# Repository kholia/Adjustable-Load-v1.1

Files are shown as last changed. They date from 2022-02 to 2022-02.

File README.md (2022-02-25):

### Variable Electronic Load

This variable electronic load helps with testing power supplies, and batteries.

Motivation: RIGOL DC Electronic Load-DL3021 costs ~50k - this project costs
nothing in comparison, and does the job in typical amateur radio contexts just
fine.

Rating: 20A @ 30V depending upon the heatsink.

Testing notes (Dhiru): I have tested my build up to 5A @ around 20v.

This is an improved version of https://www.instructables.com/DIY-Adjustable-Constant-Load-Current-Power/. All
credit goes to `GreatScott` for coming up with this project.

Note: The 3D renderings are *only* published to help with the manual layout work on
Zero-PCBs. All screenshots are clickable and zoomable.

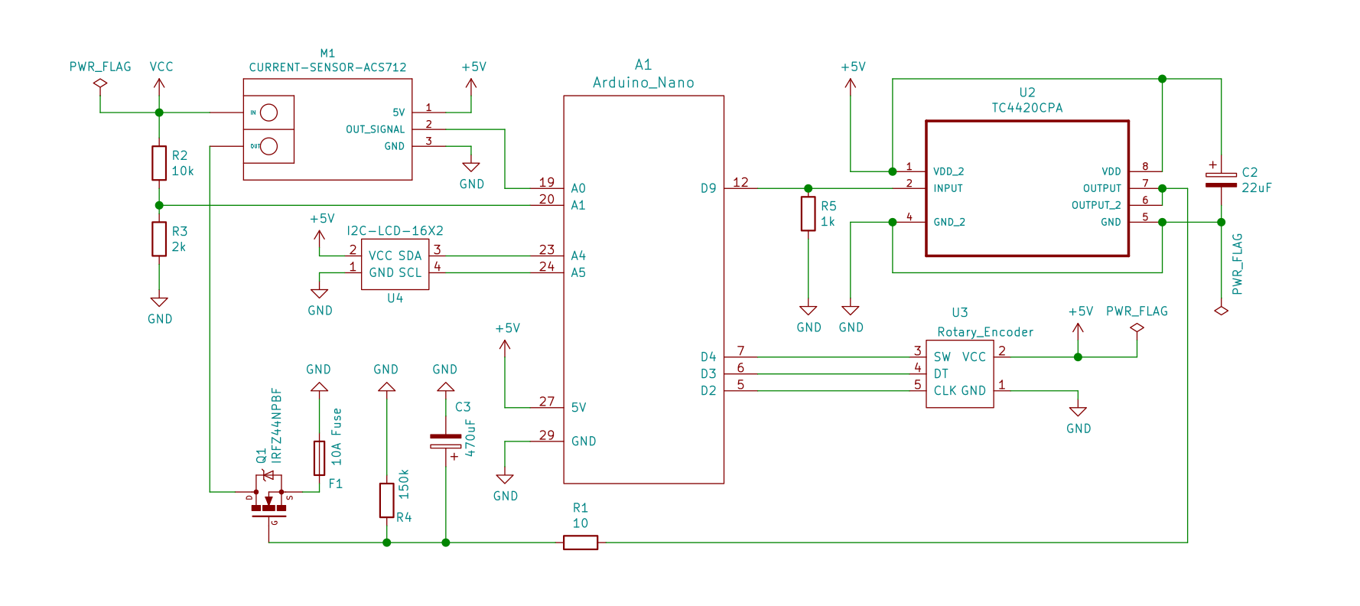
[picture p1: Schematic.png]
Schematic

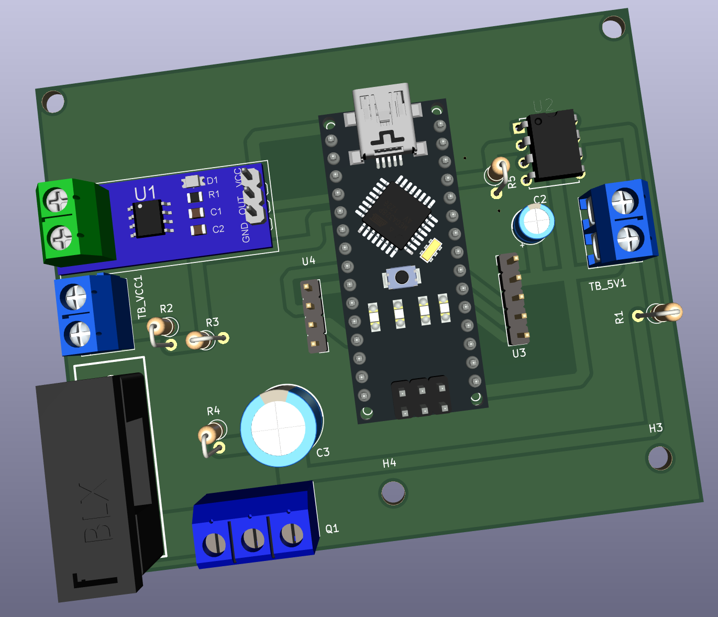
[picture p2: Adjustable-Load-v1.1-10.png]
3D rendering


See `Adjustable-Load-v1.1.pdf` for details.

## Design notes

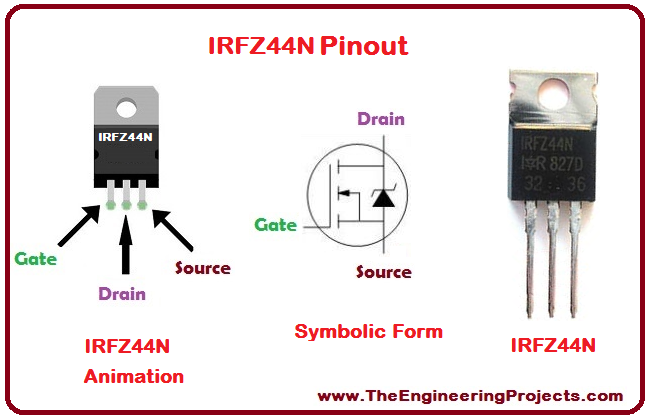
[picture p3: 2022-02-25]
images/IRFZ44N pinout.png

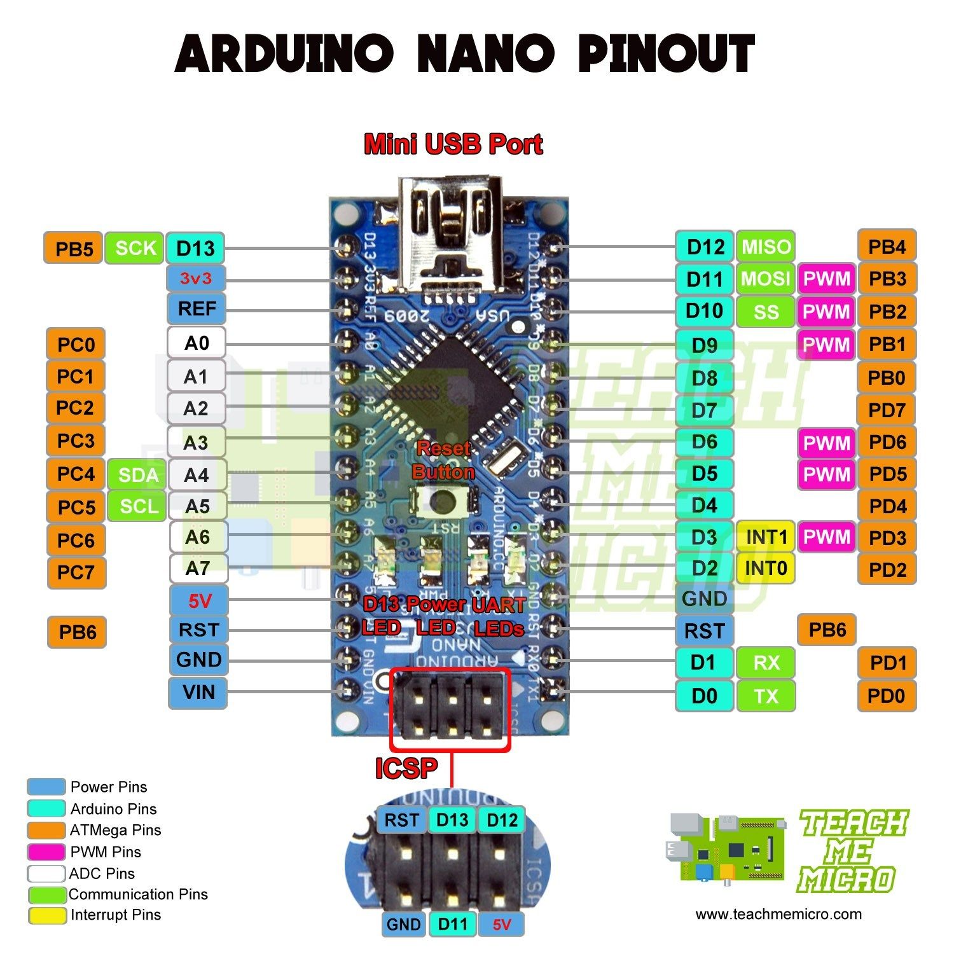
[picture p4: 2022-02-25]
images/Arduino Nano Pinout.jpg

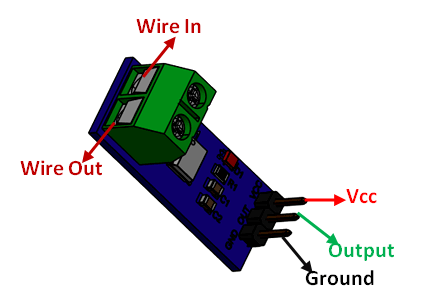
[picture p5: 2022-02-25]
images/ACS712-Current-Sensor-Pinout.png

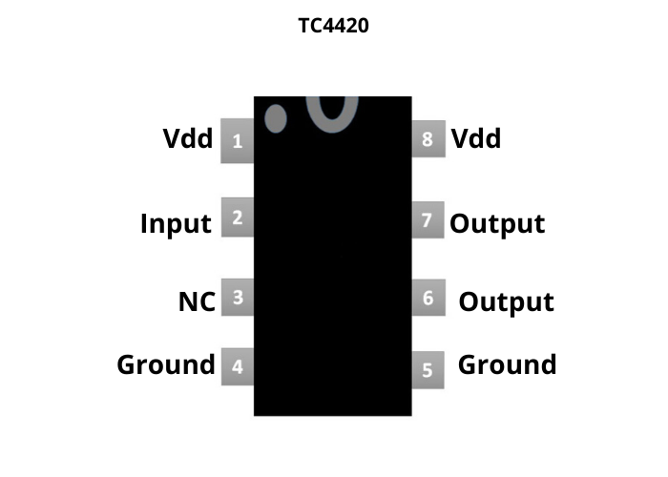
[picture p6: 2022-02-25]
images/TC4420-IC-Pinout.png

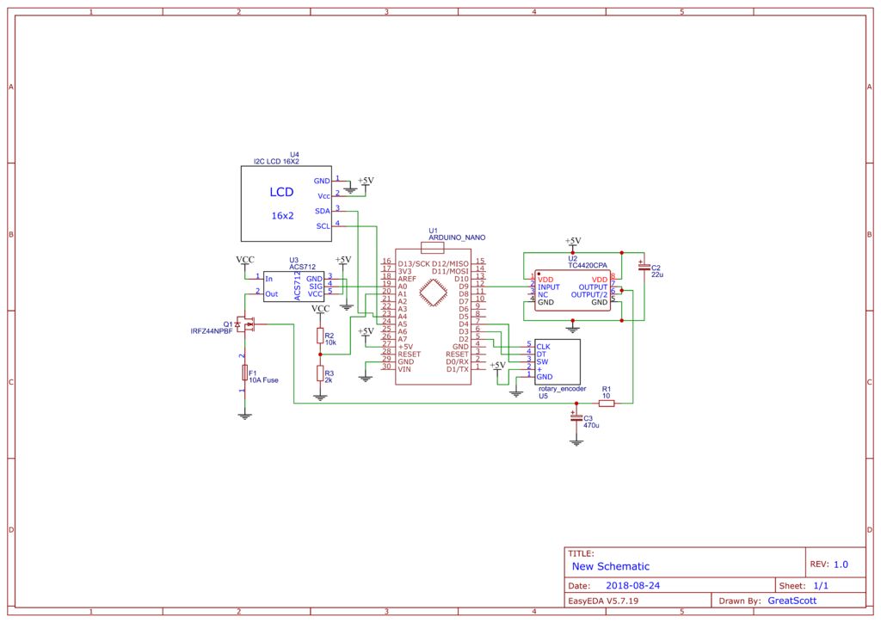
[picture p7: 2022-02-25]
Dummy Load Schematic.jpg

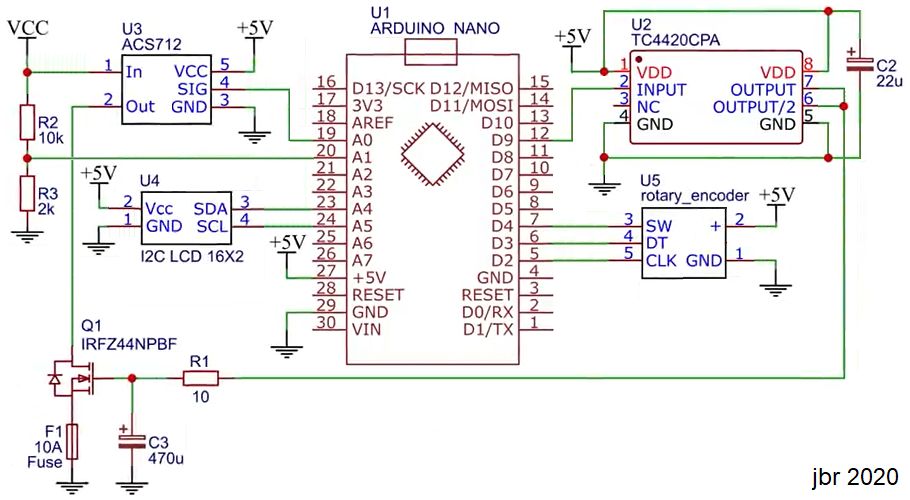
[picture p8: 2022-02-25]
Redrawn Schematic.jpg

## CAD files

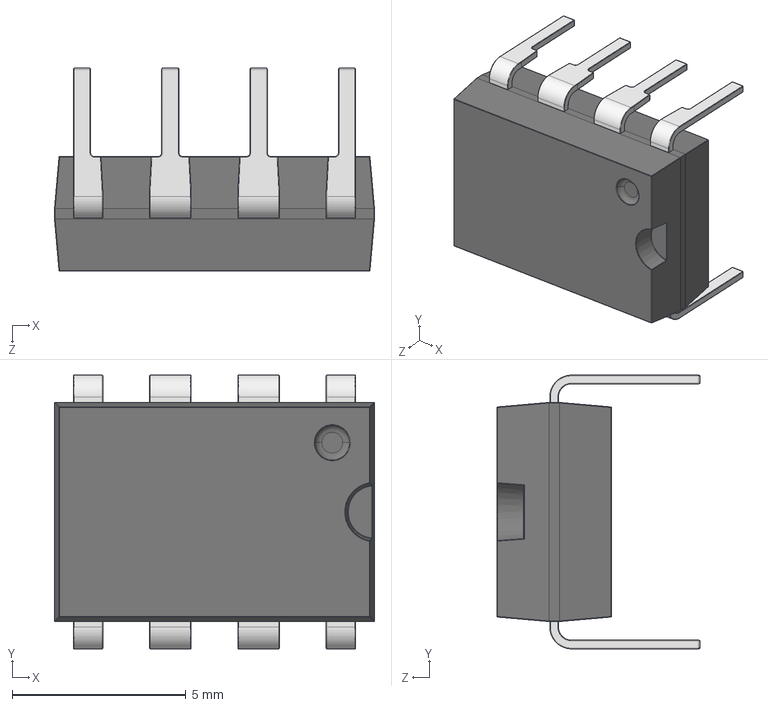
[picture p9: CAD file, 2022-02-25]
models/DIP8.STEP
9.20 x 7.87 x 5.85 mm

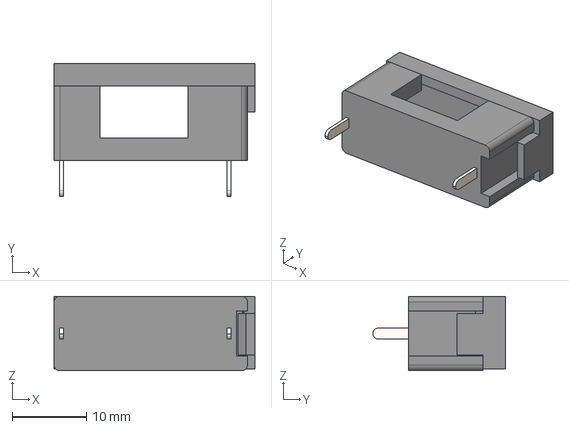
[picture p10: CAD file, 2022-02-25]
models/Fuse Holder.step
27.0 x 17.8 x 10.0 mm

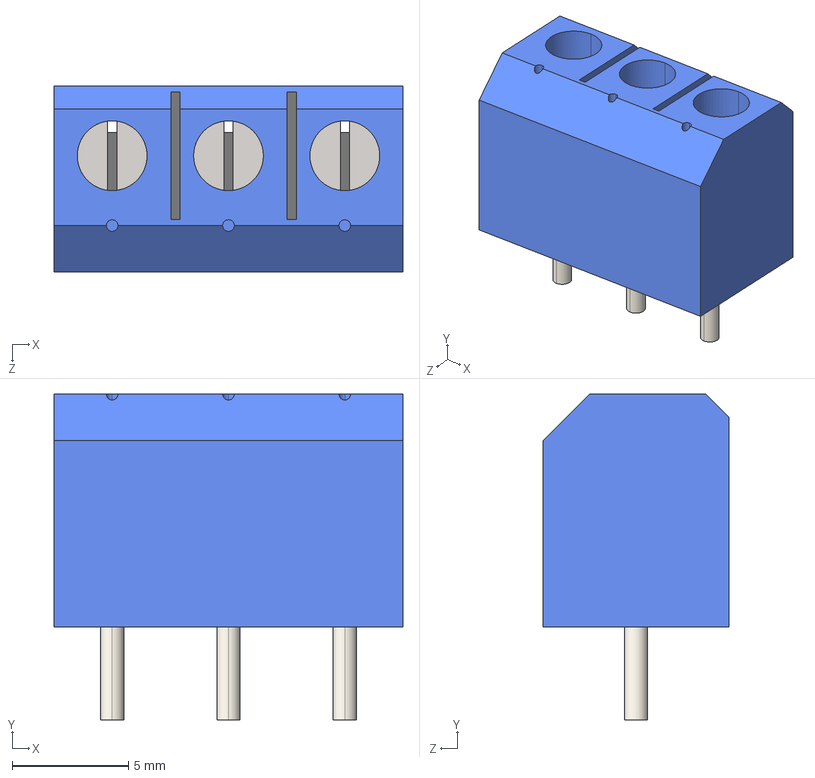
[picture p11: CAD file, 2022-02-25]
models/bornera de 3 terminales v2.0.STEP
15.0 x 14.0 x 8.00 mm

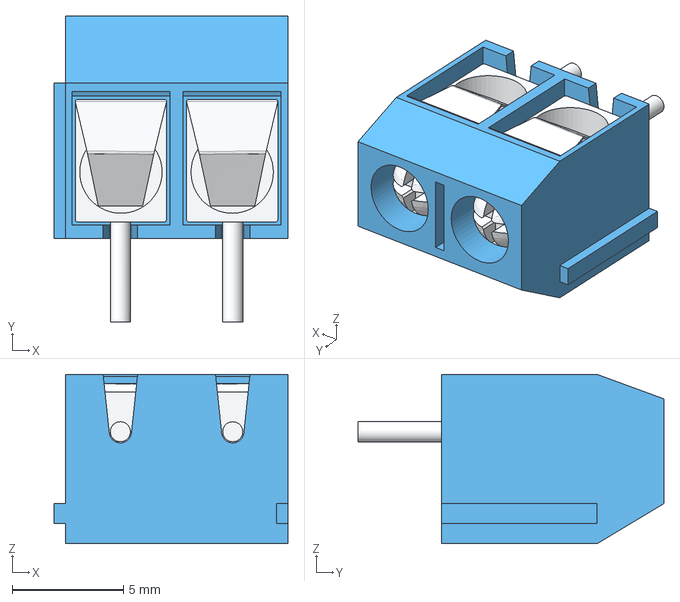
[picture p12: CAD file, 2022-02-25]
models/bornera.step
10.5 x 13.8 x 7.60 mm

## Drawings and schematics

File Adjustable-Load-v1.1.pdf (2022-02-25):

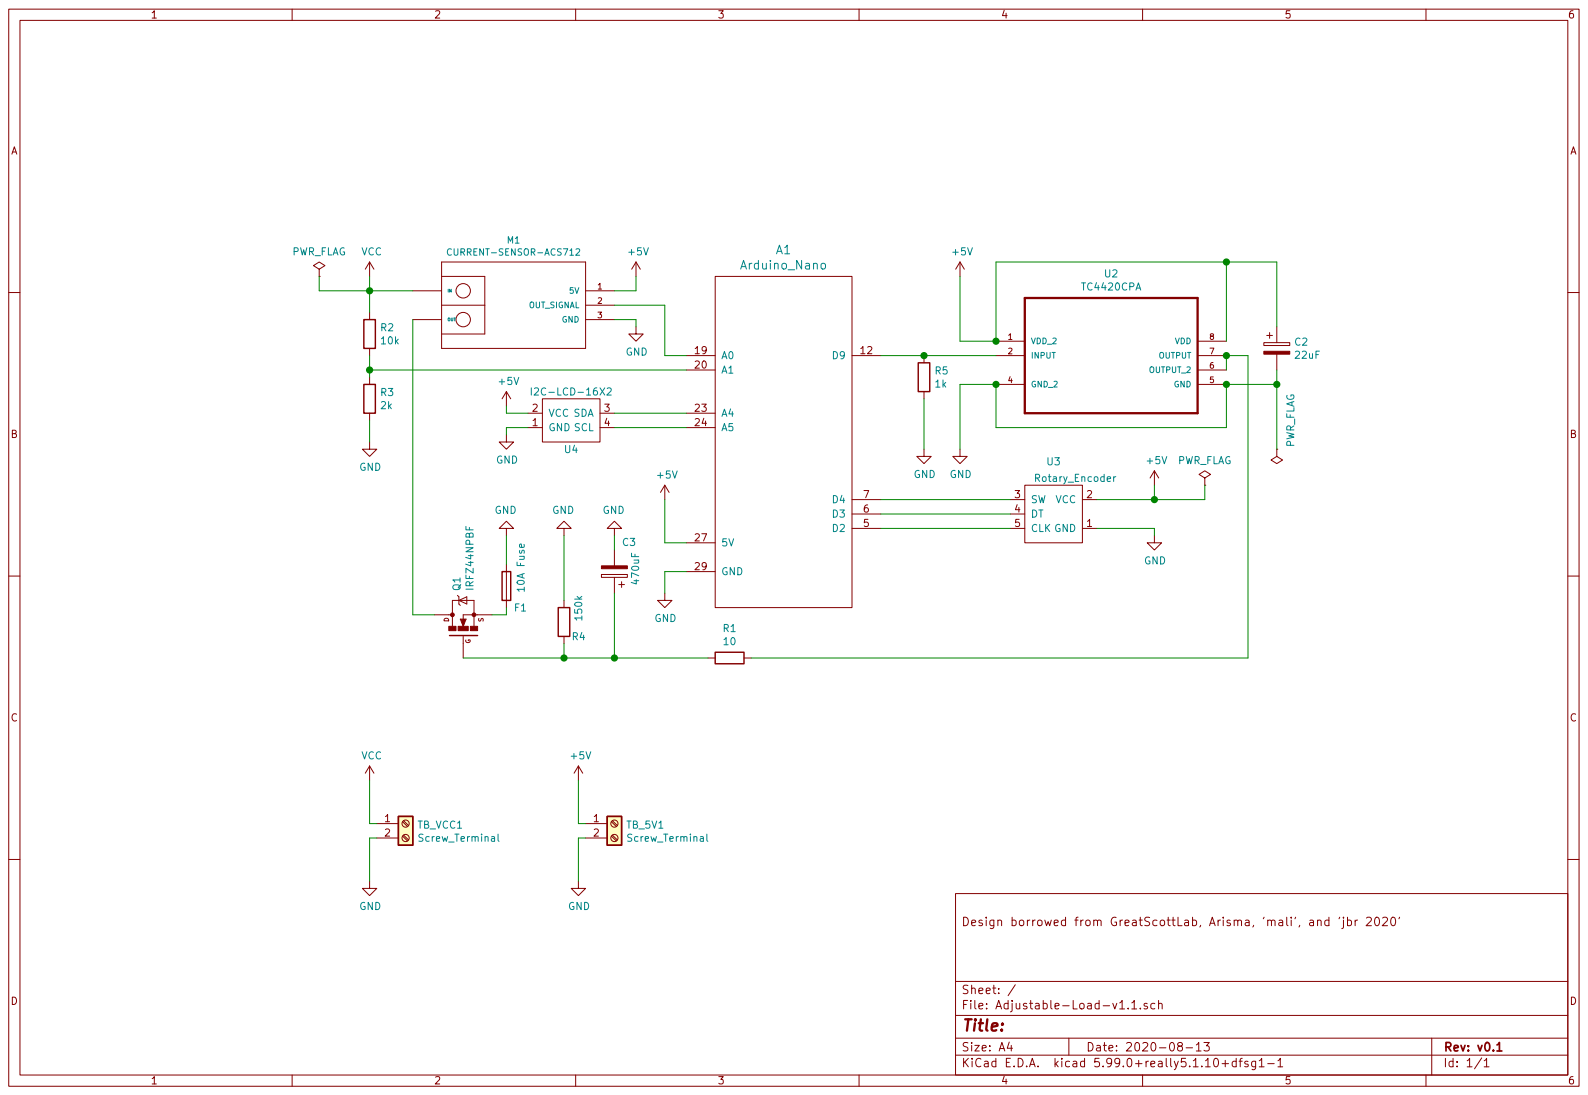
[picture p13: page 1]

File: Adjustable-Load-v1.1.sch Sheet: / Design borrowed from GreatScottLab, Arisma, 'mali', and 'jbr 2020' C3 470uF

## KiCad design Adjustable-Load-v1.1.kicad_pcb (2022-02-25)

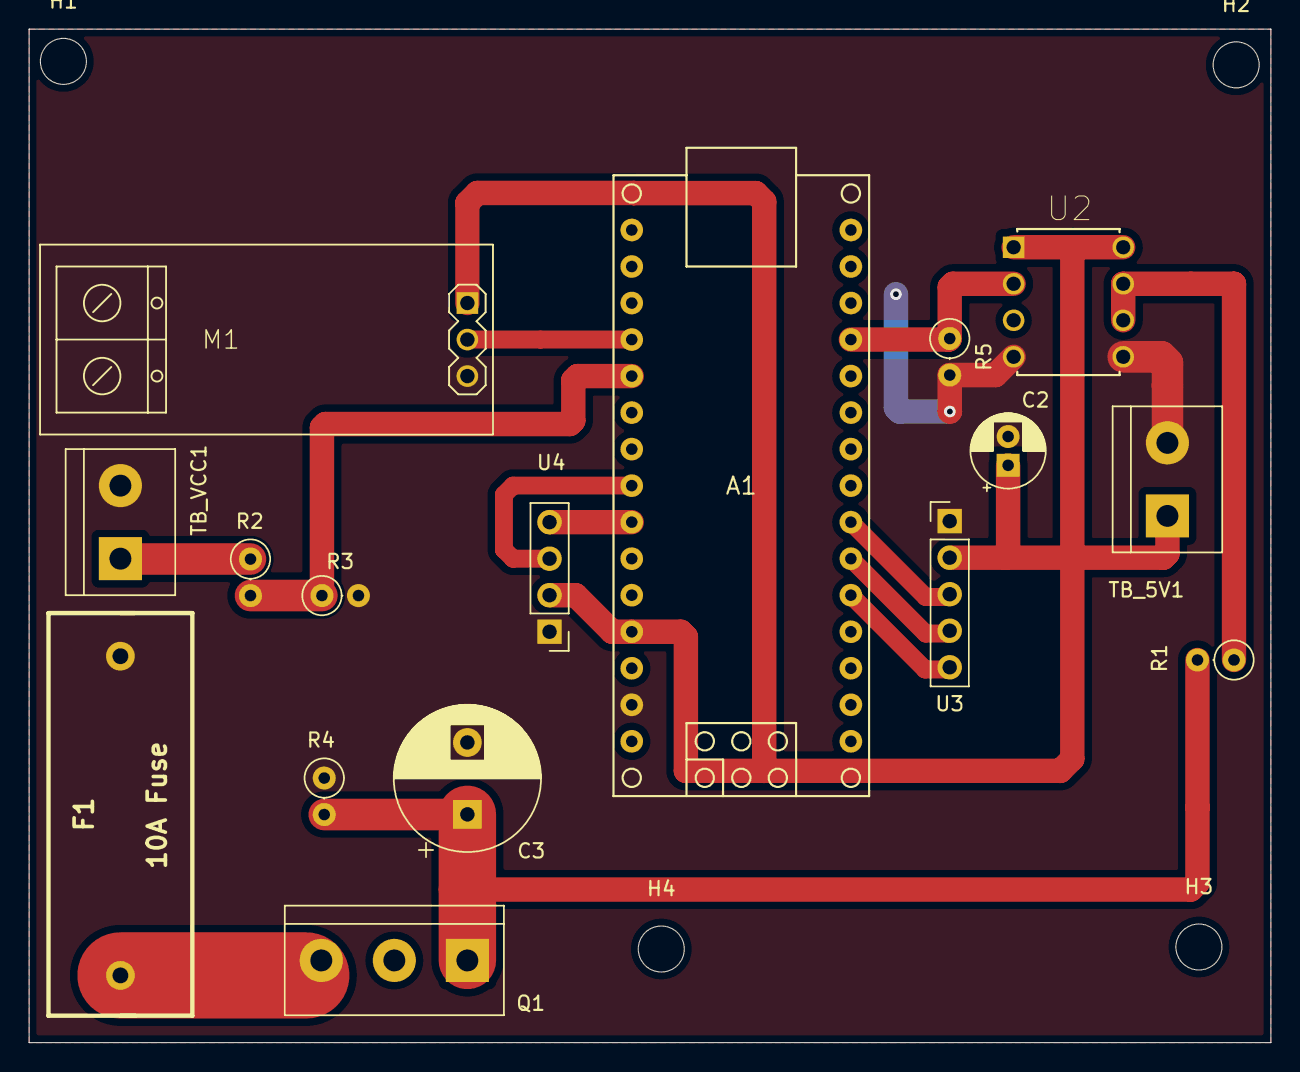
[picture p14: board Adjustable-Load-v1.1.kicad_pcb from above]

Board: 2 copper layers, 86.4 x 70.5 mm, 20 parts (0 on the bottom side), 14 nets.

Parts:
A1: Arduino_Nano; arduino_nano
C2: 22uF; CP_Radial_D5.0mm_P2.00mm
C3: 470uF; CP_Radial_D10.0mm_P5.00mm
F1: 10A Fuse; BLX-A
H1, H2, H3, H4: MountingHole; MountingHole_3.2mm_M3
M1: CURRENT-SENSOR-ACS712
Q1: IRFZ44NPBF; TerminalBlock_bornier-3_P5.08mm
R1: 10; R_Axial_DIN0207_L6.3mm_D2.5mm_P2.54mm_Vertical
R2: 10k; R_Axial_DIN0207_L6.3mm_D2.5mm_P2.54mm_Vertical
R3: 2k; R_Axial_DIN0207_L6.3mm_D2.5mm_P2.54mm_Vertical
R4: 150k; R_Axial_DIN0207_L6.3mm_D2.5mm_P2.54mm_Vertical
R5: 1k; R_Axial_DIN0207_L6.3mm_D2.5mm_P2.54mm_Vertical
TB_5V1: Screw_Terminal; TerminalBlock_bornier-2_P5.08mm
TB_VCC1: Screw_Terminal; TerminalBlock_bornier-2_P5.08mm
U2: TC4420CPA; DIP254P762X533-8
U3: Rotary_Encoder; PinHeader_1x05_P2.54mm_Vertical
U4: I2C-LCD-16X2; PinHeader_1x04_P2.54mm_Vertical

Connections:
+5V: A1.27 (5V), C2.1, M1.1 (5V), TB_5V1.1, U2.1 (VDD_2), U2.8 (VDD), U3.2 (VCC), U4.2 (VCC)
GND: A1.29 (GND), C2.2, C3.2, F1.1, M1.3 (GND), R3.2, R4.1, R5.2, TB_5V1.2, TB_VCC1.2, U2.4 (GND_2), U2.5 (GND), U3.1 (GND), U4.1 (GND)
unnamed: A1.5 (D2), U3.5 (CLK)
unnamed: A1.6 (D3), U3.4 (DT)
unnamed: A1.7 (D4), U3.3 (SW)
unnamed: A1.12 (D9), R5.1, U2.2 (INPUT)
unnamed: A1.19 (A0), M1.2 (OUT_SIGNAL)
unnamed: A1.20 (A1), R2.2, R3.1
unnamed: A1.23 (A4), U4.3 (SDA)
unnamed: A1.24 (A5), U4.4 (SCL)
unnamed: C3.1, Q1.1, R1.2, R4.2
unnamed: F1.2, Q1.3
unnamed: R1.1, U2.6 (OUTPUT_2), U2.7 (OUTPUT)
VCC: R2.1, TB_VCC1.1

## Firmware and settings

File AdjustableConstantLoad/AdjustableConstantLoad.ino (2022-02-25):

// https://www.instructables.com/id/DIY-Adjustable-Constant-Load-Current-Power/

#include <Wire.h>
#include "LiquidCrystal_I2C.h"
LiquidCrystal_I2C lcd(0x27, 16, 2);

#define clk 2
#define dt 3
#define sw 4
#define pwm 9
#define currentsense A0
#define voltagesense A1

char screen = 0;
char arrowpos = 0;
float power = 2.5;
float current = 0.250;
float curcurrent = 0;
float curpower = 0;
float curvoltage = 0;
float curcurrentraw = 0;
float zerocurrent = 510.25;  // was 514
float curvoltraw = 0;
int counter = 0;
volatile boolean currentmode = false;
volatile boolean powermode = false;
volatile boolean TurnDetected = false;
volatile boolean up = false;
volatile boolean button = false;
const unsigned char PS_128 = (1 << ADPS2) | (1 << ADPS1) | (1 << ADPS0);

/*

   Sensitivity of current sensor:

    5A = 185.00

   20A = 100.00

   30A = 66.00;

*/

float cursense = 185.00;  // for 5A current sensor

byte customChar1[8] = {
  0b10000,
  0b11000,
  0b11100,
  0b11110,
  0b11110,
  0b11100,
  0b11000,
  0b10000
};

byte customChar2[8] = {
  0b00100,
  0b01110,
  0b11111,
  0b00000,
  0b00000,
  0b11111,
  0b01110,
  0b00100,
};

ISR(PCINT2_vect) {
  if (digitalRead(sw) == LOW) {
    button = true;
  }
}

void isr0 ()  {
  TurnDetected = true;
  up = (digitalRead(clk) == digitalRead(dt));
}

void setup() {
  Serial.begin(115200);
  lcd.begin();
  pinMode(sw, INPUT_PULLUP);
  pinMode(clk, INPUT);
  pinMode(dt, INPUT);
  pinMode(pwm, OUTPUT);
  pinMode(currentsense, INPUT);
  digitalWrite(pwm, LOW);
  ADCSRA &= ~PS_128;
  ADCSRA |= (1 << ADPS1) | (1 << ADPS0);
  PCICR |= 0b00000100;
  PCMSK2 |= 0b00010000;   // turn o PCINT20(D4)
  attachInterrupt(0, isr0, RISING);
  TCCR1A = 0;
  TCCR1A = (1 << COM1A1) | (1 << WGM11);
  TCCR1B = 0;
  TCCR1B = (1 << WGM13) | (1 << WGM12) | (1 << CS10);
  ICR1 = 2047;
  OCR1A = 0;
  lcd.createChar(0, customChar1);
  lcd.createChar(1, customChar2);
  lcd.clear();
  lcd.print(" ADJ CONST LOAD");
  delay(2000);
  screen0();
  lcd.setCursor(0, 0);
  lcd.write((uint8_t)0);

  // Read the analog input a few times to makes sure that we get
  // a good zero adjustment from nominal center value. There should be no
  // current flowing while this is happening.
  // for (uint8_t i = 1; i <= 10; i++) {
  //    uint16_t error = 512 - analogRead(SENSOR_PIN);
  //    sensorZeroAdj = ((sensorZeroAdj * (i-1)) + error)/i;
  // }
}

void loop() {

  if (currentmode) {
    // take 20 readings of current
    curcurrentraw = 0;
    for (int i = 0; i < 20; i++) {
      analogRead(currentsense);
      curcurrentraw += analogRead(currentsense);
    }
    // 5V -> 5000mV
    // 100.00 -> sensitivity (20A current sensor)
    // curcurrent = (((curcurrentraw/20) - zerocurrent) * (5000.00 / 1023.00) / 100.00);
    curcurrent = (((curcurrentraw / 20) - zerocurrent) * (5000.00 / 1023.00) / cursense);

    if (curcurrent < 0)
      curcurrent = 0;

    // curcurrentraw = analogRead(currentsense);
    // curcurrent = ((curcurrentraw - zerocurrent) * (5000.00 / 1023.00) / 100.00);
    //Serial.print(zerocurrent);
    //Serial.print("  ");
    //Serial.print(curcurrentraw);
    //Serial.print("  ");
    //Serial.println(curcurrent);
    if (counter == 5000) {
      lcd.setCursor(4, 1);
      lcd.print(curcurrent);
      lcd.print("A ");
      counter = 0;
      Serial.println(curcurrentraw / 20);
      Serial.println(curcurrent);
    }
    if (curcurrent < current) {
      OCR1A++;
    }
    else {
      if (OCR1A > 0) {
        OCR1A = OCR1A - 1;
      } else {
        OCR1A = 0;
      }
    }
    counter++;
    delayMicroseconds(100);
  }

  if (powermode) {
    /* curcurrentraw = analogRead(currentsense);
       curcurrent = ((curcurrentraw - zerocurrent) * (5000.00 / 1023.00) / 100.00); */
    // take 20 readings of current
    curcurrentraw = 0;
    for (int i = 0; i < 20; i++) {
      curcurrentraw += analogRead(currentsense);
    }
    curcurrent = (((curcurrentraw / 20) - zerocurrent) * (5000.00 / 1023.00) / 100.00);

    if (curcurrent < 0)
      curcurrent = 0;
    /* read twice */
    curvoltraw = analogRead(voltagesense);
    curvoltraw = analogRead(voltagesense);
    curvoltage = curvoltraw * (5000.00 / 1023.00) * 7.20 / 1000.00;
    curpower = curvoltage * curcurrent;
    //Serial.println(curpower);
    if (counter == 5000) {
      lcd.setCursor(4, 1);
      lcd.print(curpower);
      lcd.print("W ");
      counter = 0;

      Serial.println(curcurrentraw / 20);
      Serial.println(curcurrent);
      Serial.println(curvoltraw);
      Serial.println(curvoltage);
      Serial.println(curpower);
      Serial.println("-----");
    }
    if (curpower < power) {
      OCR1A++;
    }
    else {
      if (OCR1A > 0) {
        OCR1A = OCR1A - 1;
      } else {
        OCR1A = 0;
      }
    }
    counter++;
    delayMicroseconds(100);
  }

  if (TurnDetected) {
    delay(200);
    switch (screen) {
      case 0:
        switch (arrowpos) {
          case 0:
            if (!up) {
              screen0();
              lcd.setCursor(0, 1);
              lcd.write((uint8_t)0);
              arrowpos = 1;
            }
            break;
          case 1:
            if (up) {
              screen0();
              lcd.setCursor(0, 0);
              lcd.write((uint8_t)0);
              arrowpos = 0;
            }
            break;
        }
        break;
      case 1:
        switch (arrowpos) {
          case 0:
            if (!up) {
              screen1();
              lcd.setCursor(0, 1);
              lcd.write((uint8_t)0);
              arrowpos = 1;
            }
            break;
          case 1:
            if (up) {
              screen1();
              lcd.setCursor(0, 0);
              lcd.write((uint8_t)0);
              arrowpos = 0;
            }
            else {
              screen1();
              lcd.setCursor(7, 1);
              lcd.write((uint8_t)0);
              arrowpos = 2;
            }
            break;
          case 2:
            if (up) {
              screen1();
              lcd.setCursor(0, 1);
              lcd.write((uint8_t)0);
              arrowpos = 1;
            }
            break;
        }
        break;
      case 2:
        if (up) {
          power = power + 0.1;
          lcd.setCursor(7, 0);
          lcd.print(power);
          lcd.print("W");
          lcd.write((uint8_t)1);
          lcd.print("  ");
        }
        else {
          power = power - 0.1;
          if (power < 0) {
            power = 0;
          }
          lcd.setCursor(7, 0);
          lcd.print(power);
          lcd.print("W");
          lcd.write((uint8_t)1);
          lcd.print("  ");
        }
        break;
      case 4:
        switch (arrowpos) {
          case 0:
            if (!up) {
              screen4();
              lcd.setCursor(0, 1);
              lcd.write((uint8_t)0);
              arrowpos = 1;
            }
            break;
          case 1:
            if (up) {
              screen4();
              lcd.setCursor(0, 0);
              lcd.write((uint8_t)0);
              arrowpos = 0;
            }
            else {
              screen4();
              lcd.setCursor(7, 1);
              lcd.write((uint8_t)0);
              arrowpos = 2;
            }
            break;
          case 2:
            if (up) {
              screen4();
              lcd.setCursor(0, 1);
              lcd.write((uint8_t)0);
              arrowpos = 1;
            }
            break;
        }
        break;
      case 5:
        if (up) {
          current = current + 0.1;
          lcd.setCursor(9, 0);
          lcd.print(current);
          lcd.print("A");
          lcd.write((uint8_t)1);
          lcd.print(" ");
        }
        else {
          current = current - 0.1;
          if (current < 0) {
            current = 0;
          }
          lcd.setCursor(9, 0);
          lcd.print(current);
          lcd.print("A");
          lcd.write((uint8_t)1);
          lcd.print(" ");
        }
        break;
    }
    TurnDetected = false;
  }

  if (button) {
    delay(200);
    switch (screen) {
      case 0:
        if (arrowpos == 0) {
          screen = 1;
          screen1();
          lcd.setCursor(0, 0);
          lcd.write((uint8_t)0);
        }
        else {
          screen = 4;
          screen4();
          lcd.setCursor(0, 0);
          lcd.write((uint8_t)0);
        }
        break;
      case 1:
        switch (arrowpos) {
          case 0:
            screen = 2;
            screen2();
            break;
          case 1:
            powermode = true;
            screen = 3;
            screen3();
            break;
          case 2:
            screen = 0;
            screen0();
            lcd.setCursor(0, 0);
            lcd.write((uint8_t)0);
            break;
        }
        break;
      case 2:
        screen = 1;
        screen1();
        lcd.setCursor(0, 0);
        lcd.write((uint8_t)0);
        break;
      case 3:
        powermode = false;
        OCR1A = 0;
        counter = 0;
        screen = 1;
        screen1();
        lcd.setCursor(0, 0);
        lcd.write((uint8_t)0);
        break;
      case 4:
        switch (arrowpos) {
          case 0:
            screen = 5;
            screen5();
            break;
          case 1:
            screen = 6;
            screen6();
            currentmode = true;
            counter = 0;
            break;
          case 2:
            screen = 0;
            screen0();
            lcd.setCursor(0, 0);
            lcd.write((uint8_t)0);
            break;
        }
        break;
      case 5:
        screen = 4;
        screen4();
        lcd.setCursor(0, 0);
        lcd.write((uint8_t)0);
        break;
      case 6:
        screen = 4;
        screen4();
        lcd.setCursor(0, 0);
        lcd.write((uint8_t)0);
        currentmode = false;
        OCR1A = 0;
        break;
    }
    arrowpos = 0;
    button = false;
  }
}

void screen0() {
  lcd.clear();
  lcd.setCursor(1, 0);
  lcd.print("Power Mode");
  lcd.setCursor(1, 1);
  lcd.print("Current Mode");
}

void screen1() {
  lcd.clear();
  lcd.setCursor(1, 0);
  lcd.print("Power:");
  lcd.print(power);
  lcd.print("W");
  lcd.setCursor(1, 1);
  lcd.print("Start");
  lcd.setCursor(8, 1);
  lcd.print("Back");
}

void screen2() {
  lcd.clear();
  lcd.setCursor(1, 0);
  lcd.print("Power:");
  lcd.print(power);
  lcd.print("W");
  lcd.write((uint8_t)1);
}

void screen3() {
  lcd.clear();
  lcd.print("Set:");
  lcd.print(power);
  lcd.print("W");
  lcd.setCursor(0, 1);
  lcd.print("Cur:");
  lcd.print(curpower);
  lcd.print("W");
  lcd.setCursor(11, 1);
  lcd.write((uint8_t)0);
  lcd.print("STOP");
}

void screen4() {
  lcd.clear();
  lcd.setCursor(1, 0);
  lcd.print("Current:");
  lcd.print(current);
  lcd.print("A");
  lcd.setCursor(1, 1);
  lcd.print("Start");
  lcd.setCursor(8, 1);
  lcd.print("Back");
}

void screen5() {
  lcd.clear();
  lcd.setCursor(1, 0);
  lcd.print("Current:");
  lcd.print(current);
  lcd.print("A");
  lcd.write((uint8_t)1);
}

void screen6() {
  lcd.clear();
  lcd.print("Set:");
  lcd.print(current);
  lcd.print("A");
  lcd.setCursor(0, 1);
  lcd.print("Cur:");
  lcd.print(curcurrent);
  lcd.print("A");
  lcd.setCursor(11, 1);
  lcd.write((uint8_t)0);
  lcd.print("STOP");
}
